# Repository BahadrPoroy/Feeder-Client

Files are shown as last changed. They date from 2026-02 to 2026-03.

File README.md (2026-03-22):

# 🕒 NetTime Ecosystem - Feeder Client (V1.2.0) 🐟






A **cloud-connected smart actuator node** based on **ESP8266**. This device is a critical peripheral in the NetTime ecosystem, responsible for executing automated feeding cycles and maintaining a persistent global state via **Firebase Realtime Database**.

## 🚀 What's New in v1.2.0
<!--### FIXES ###
- **`START_VAL`, `SPEED_LIMIT` and `REVERSE_VAL` values are refactored, `START_VAL` is increased to 125 from 120 for faster first movement and easier escaping, `SPEED_LIMIT` is reduced to 110 from 115 for more consistent stopping on switch also, `REVERSE_VAL` is increased to 70 from 60 for same reason as `SPEED_LIMIT`**
-->
### IMPROVEMENTS ###
<!--- **Detailed and improved fault detection system:**
    - ***In `dispensePortion` function, `millis()` based control used instead of `delay(2000)` for `non-blocking` principle. Added a fault control section to detect switch state changes..***
    - **Error detection messages has been improved from now on, they include more information *If the `switch released` control (the first one) detects an error, message includes `servo/switch error` notification else, if `is switch re-triggered` control detects an error the message includes `possible_servo_stuck` information***
- **`is switch re-triggered` control's timeout value is changed, now it's reduced to ten seconds for more reliable and realistic results**
- **Added a Restart function to automatically calibrate and return the servo to its home position upon system initialization or recovery.**
-->
   - **Integrated an RGB LED as a real-time status indicator. The system now provides visual feedback: flashing $\color{blue}{\text{blue}}$ during Wi-Fi negotiation, turning solid $\color{blue}{\text{blue}}$ once connected. Other states include $\color{red}{\text{red}}$ for hardware/software errors, $\color{yellow}{\text{yellow}}$ for pending operations, and $\color{green}{\text{green}}$ for successful task completion.**

### 🚀 Key Features

* **Asynchronous State Synchronization:** Monitors cloud-based triggers in real-time. It uses a **Universal State Template** to ensure the feeding status is synchronized across all dashboard clients.
* **Hardware Actuation:** Manages high-precision motor/servo control for the physical feeding mechanism.
* **Decoupled Architecture:** Operates as a standalone agent. While it integrates with the [NetTime-Env-Server](https://github.com/BahadrPoroy/NetTime-Env-Server), it can function independently through direct web-dashboard commands.
* **Persistent Event Logging:** Automatically stamps and uploads `lastFedTime` and `isFed` status to the cloud, ensuring data persistence even after power cycles.
* **Network Resilience:** Features an automated reconnection engine for both WiFi and Firebase services to prevent missed feeding cycles.
* **Status LED:** Integrated an RGB indicator to provide real-time visual feedback, significantly enhancing the `User Experience (UX)`.
---

### 🏗️ System Architecture

The Feeder Client follows the **Publisher-Subscriber** model:
1.  **Listen:** Subscribes to the `isFed` trigger on Firebase.
2.  **Act:** Once triggered, executes the motor rotation sequence.
3.  **Confirm:** Updates the database with the success timestamp and resets the trigger.

---

### 🛠️ Hardware Requirements

* **MCU:** ESP8266 (NodeMCU or Wemos D1 Mini)
* **Actuator:** MG90S Servo or Stepper Motor (Configurable in `HardwareConfig.h`)
* **Power:** 5V External DC (Recommended for motor stability)

---

### 🎨 Industrial Design & Prototyping

To ensure a professional and durable finish, the enclosures for all ecosystem nodes (Server, Feeder, and Display) were **custom-designed and 3D printed**.

* **Custom Enclosures:** Specifically tailored to house the ESP8266, sensors, and actuators while maintaining optimal airflow and structural integrity.
* **Rapid Prototyping:** Iterative design process to ensure perfect fitment for the MG90S servo and OLED mounts.
* **Integration:** The hardware is not just a circuit on a breadboard; it is a fully enclosed, desk-ready consumer electronics prototype.

---

## 📂 Project Structure

```
Feeder_Client
├── NetworkManager.h  # Firebase, WiFi, UDP & OTA Updates
```

---

🌐 The NetTime Ecosystem
This client is designed to work within the NetTime IoT Framework. While it can operate as a standalone node, it reaches its full potential when paired with other ecosystem components:

[NetTime-Env-Server](https://github.com/BahadrPoroy/NetTime-Env-Server): The central hub that provides localized time, environmental data, and acts as the primary network master.

[NetTime-Client-Display](https://github.com/BahadrPoroy/NetTime-Client-Display): A dedicated monitoring node that visualizes real-time climate data and synchronized time on a peripheral OLED/TFT display.

NetTime-Feeder-Client (This Repo): The ecosystem's actuator node, responsible for cloud-triggered hardware automation and persistent state logging.

[Web Dashboard](https://bahadrporoy.github.io/NetTime-Env-Server/): A real-time interface (integrated within the Server) that allows manual overrides and global monitoring of all connected clients.

---

### 🔧 Installation & Deployment

1.  **Clone** this repository.
2.  **Configure Credentials:** Create a `secrets.h` file based on the template provided.
3.  **Hardware Calibration:** Adjust motor sweep angles or steps in `config.h`.
4.  **Flash:** Deploy via Arduino IDE or PlatformIO.

---

### 📄 License
This project is licensed under the **MIT License**.

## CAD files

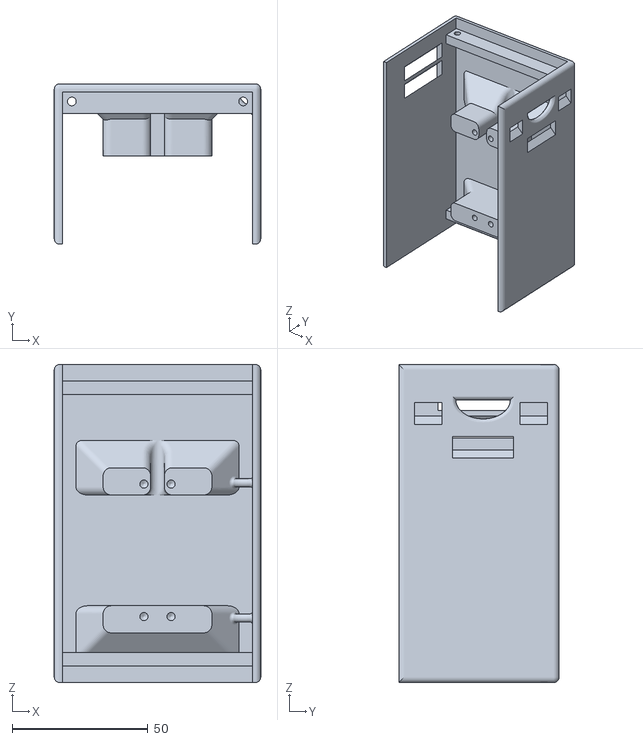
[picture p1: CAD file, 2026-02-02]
3d-models/Main_Body.STL
76.0 x 59.0 x 117.0

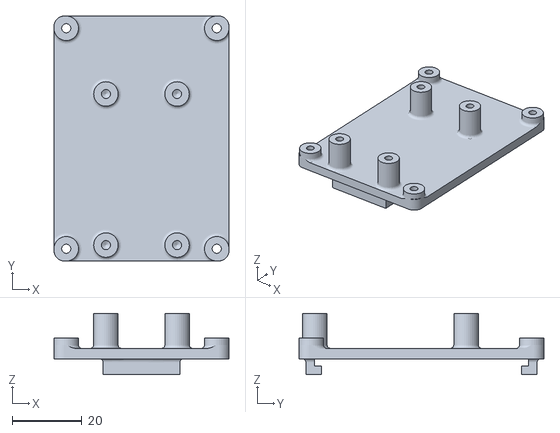
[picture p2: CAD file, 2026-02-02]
3d-models/Button_Base.STL
50.0 x 70.0 x 17.5

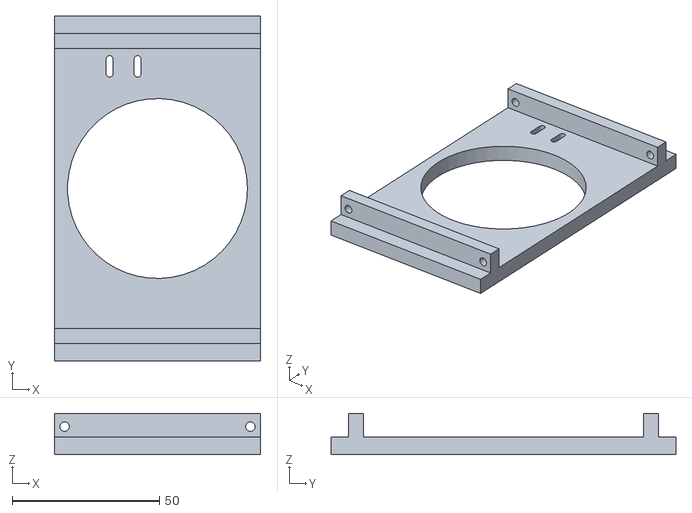
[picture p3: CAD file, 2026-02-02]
3d-models/Front_Panel.STL
70.0 x 117.0 x 14.0

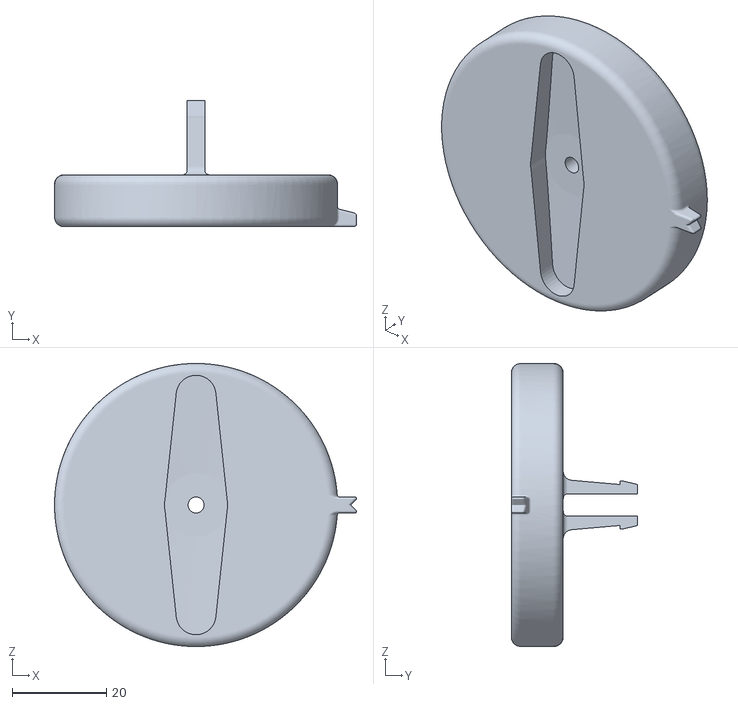
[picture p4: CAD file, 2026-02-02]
3d-models/Feeder_Coupler.STL
64.0 x 26.8 x 60.0

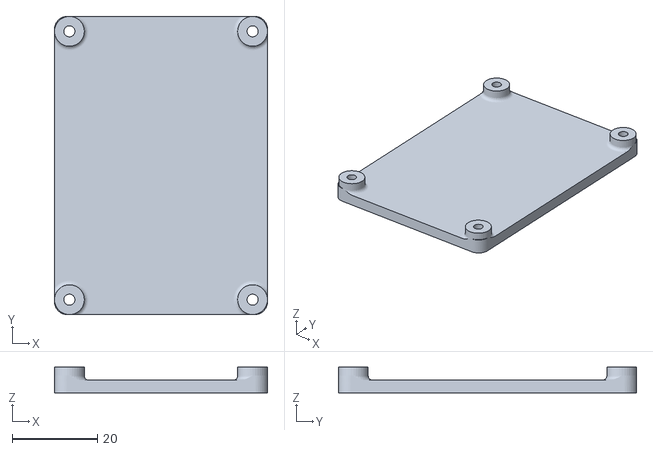
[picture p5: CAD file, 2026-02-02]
3d-models/Top_Cover.STL
50.0 x 70.0 x 6.00

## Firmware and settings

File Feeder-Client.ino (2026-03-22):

#include <ESP8266WiFi.h>
#include <WiFiUdp.h>
#include <ArduinoOTA.h>
#include <Servo.h>
#include <time.h>
#include "secrets.h"
#include "NetworkManager.h"

// --- Hardware Pins ---
const int SERVO_PIN = D2;
const int SWITCH_PIN = D1;  // D1 and GND connection
const int L_RED = D3;
const int L_GREEN = D5;
const int L_BLUE = D6;

Servo feederServo;
NetworkManager netBox;

// --- System Settings ---
String Status = "IDLE";
long int lastFirebaseSync = 0;
unsigned long lastPacketTime = 0;
int lastCheckDay = -1;
int lastCheckInterval = 0;
int dailyFeedCount = 10;
int dailyFeedLimit = 1;

// --- Servo Settings ---
const int STOP_VAL = 90;
const int START_VAL = 125;
const int REVERSE_VAL = 60;
const int SPEED_LIMIT = 110;

// --- Time Settings ---
struct tm timeinfo;
const char* ntpServer = "pool.ntp.org";
const long gmtOffset_sec = 3 * 3600;


void setup() {
  pinMode(L_RED, OUTPUT);
  pinMode(L_GREEN, OUTPUT);
  pinMode(L_BLUE, OUTPUT);
  netBox.begin();
  Serial1.begin(115200);
  Serial.begin(115200);

  configTime(gmtOffset_sec, 0, ntpServer);

  pinMode(SWITCH_PIN, INPUT_PULLUP);

  feederServo.attach(SERVO_PIN);

  Restart();  //Gets the servo to home position

  netBox.readFeedLimit(dailyFeedLimit);
  netBox.readFeedCount(dailyFeedCount);
  if (dailyFeedCount == dailyFeedLimit)
    netBox.broadcastUDP("SUCCESS");
}

void dispensePortion() {
  digitalWrite(L_RED, LOW);
  digitalWrite(L_GREEN, LOW);
  digitalWrite(L_BLUE, HIGH);
  if (dailyFeedCount >= dailyFeedLimit) {
    netBox.broadcastUDP("SUCCESS");
    digitalWrite(L_RED, HIGH);
    digitalWrite(L_GREEN, LOW);
    digitalWrite(L_BLUE, HIGH);
    return;
  }
  Status = "PENDING";
  netBox.broadcastUDP(Status);

  // --- Clearing The Switch Area ---

  unsigned long timeout = millis();

  while (millis() - timeout <= 2000) {
    feederServo.write(START_VAL);
  }
  // --- ~ ~ ~ ---

  if (digitalRead(SWITCH_PIN) == HIGH) {  //Controls the system for any stucks
    feederServo.write(STOP_VAL);
    Status = "ERROR_HARDWARE(Servo/Switch_Error)";
    netBox.broadcastUDP(Status);
    netBox.updateFirebase(Status);
    digitalWrite(L_RED, LOW);
    digitalWrite(L_GREEN, HIGH);
    digitalWrite(L_BLUE, HIGH);
    return;
  }

  timeout = millis();
  int slowFact = 0;

  while (digitalRead(SWITCH_PIN) == LOW) {
    if (millis() - timeout > 10000) {  // 10 second safety timeout
      Serial1.println("ERROR: Switch not triggered!");
      Status = "ERROR_HARDWARE(Possible_Servo_Stuck)";
      break;
    }
    feederServo.write(START_VAL - slowFact);
    slowFact++;
    if (START_VAL - slowFact <= SPEED_LIMIT) slowFact = START_VAL - SPEED_LIMIT;
    yield();
  }

  feederServo.write(STOP_VAL);  // Always stop

  if (Status == "PENDING") {
    Status = "SUCCESS";
    dailyFeedCount++;
    netBox.updateFirebase(dailyFeedCount);
  }

  netBox.broadcastUDP(Status);
  netBox.updateFirebase(Status);
  Serial1.print("Dispense finished with status: ");
  Serial1.println(Status);
  if (Status.startsWith("ERROR")) {  //Red
    digitalWrite(L_RED, LOW);
    digitalWrite(L_GREEN, HIGH);
    digitalWrite(L_BLUE, HIGH);
  } else if (Status == "SUCCESS") {  // Green
    digitalWrite(L_RED, HIGH);
    digitalWrite(L_GREEN, LOW);
    digitalWrite(L_BLUE, HIGH);
  } else {  // Yellow
    digitalWrite(L_RED, LOW);
    digitalWrite(L_GREEN, LOW);
    digitalWrite(L_BLUE, HIGH);
  }
}

void loop() {
  netBox.handleOTA();
  netBox.handleNetwork(Status, lastPacketTime);
  if (millis() - lastCheckInterval >= 1000) {
    lastCheckInterval = millis();
    time_t now = time(nullptr);
    localtime_r(&now, &timeinfo);
  }
  if (Status == "SUCCESS" && (millis() - lastPacketTime > 600000)) {
    Status = "IDLE";
    digitalWrite(L_RED, HIGH);
    digitalWrite(L_GREEN, LOW);
    digitalWrite(L_BLUE, LOW);
    netBox.broadcastUDP(Status);
    Serial1.println("Cooldown finished. System is IDLE again.");
  }
  if (millis() - lastFirebaseSync >= 20000) {
    lastFirebaseSync = millis();
    netBox.readFeedLimit(dailyFeedLimit);
  }
  if (timeinfo.tm_hour == 0 && timeinfo.tm_min == 0 && lastCheckDay != timeinfo.tm_wday) {
    lastCheckDay = timeinfo.tm_wday;
    Status = "IDLE";
    dailyFeedCount = 0;
    netBox.broadcastUDP(Status);
    netBox.updateFirebase(Status);
    netBox.updateFirebase(dailyFeedCount);
    digitalWrite(L_RED, HIGH);
    digitalWrite(L_GREEN, HIGH);
    digitalWrite(L_BLUE, LOW);
  }
}

void Restart() {
  unsigned long timeout = millis();
  while (digitalRead(SWITCH_PIN) == LOW) {
    feederServo.write(REVERSE_VAL);
    if (millis() - timeout > 15000) {  // 10 second safety timeout
      Serial1.println("ERROR: Switch not triggered!");
      Status = "ERROR_HARDWARE(Possible_Servo_Stuck)";
      break;
    }
    yield();
  }
  feederServo.write(STOP_VAL);  // Servo Initial State
  Status = "IDLE";
  netBox.broadcastUDP(Status);
  netBox.updateFirebase(Status);
  if (Status.startsWith("ERROR")) {
    digitalWrite(L_RED, LOW);
    digitalWrite(L_GREEN, HIGH);
    digitalWrite(L_BLUE, HIGH);
  } else {
    digitalWrite(L_RED, HIGH);
    digitalWrite(L_GREEN, HIGH);
    digitalWrite(L_BLUE, LOW);
  }
}

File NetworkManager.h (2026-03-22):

#ifndef NETWORK_MANAGER_H
#define NETWORK_MANAGER_H

#include <ESP8266WiFi.h>
#include <FirebaseESP8266.h>
#include <ArduinoOTA.h>
#include <WiFiUdp.h>
#include <ESP8266HTTPClient.h>
#include <WiFiClientSecure.h>
#include <ArduinoJson.h>
#include "secrets.h"

extern void dispensePortion();
extern void Restart();
extern const int L_RED;
extern const int L_BLUE;
extern const int L_GREEN;

class NetworkManager {
private:
  FirebaseData firebaseData;
  FirebaseConfig config;
  FirebaseAuth auth;
  WiFiUDP udp;

  //Seperated ports for diffrent purposes
  unsigned int INCOMING_PORT = 4210;  //Listening port for Client
  unsigned int OUTGOING_PORT = 4211;  //Sending port for Client
                                      /**
   * @brief Fetches weather data from OpenWeather API using stream parsing to save RAM
   */

public:

  void begin() {
    digitalWrite(L_RED, HIGH);
    digitalWrite(L_GREEN, HIGH);
    digitalWrite(L_BLUE, HIGH);
    int now = millis();
    WiFi.mode(WIFI_STA);
    WiFi.begin(YOUR_SSID, YOUR_PASS);

    Serial.print("Connecting to WiFi");
    while (WiFi.status() != WL_CONNECTED) {
      if (millis() - now >= 500) {
        digitalWrite(L_BLUE, !digitalRead(L_BLUE));
        now = millis();
      }
      delay(10);
    }
    Serial.println("\nWiFi Connected");
    digitalWrite(L_BLUE, LOW);

    config.host = YOUR_URL;
    config.signer.tokens.legacy_token = YOUR_DATABASE_SECRET_KEY;
    Firebase.begin(&config, &auth);
    Firebase.reconnectWiFi(true);

    ArduinoOTA.setHostname("Feeder_Client");
    ArduinoOTA.setPassword(YOUR_OTA_PASS);

    ArduinoOTA.begin();
    udp.begin(INCOMING_PORT);
  }

  void updateFirebase(const String &Status) {
    Firebase.setString(firebaseData, "/FeederStatus/Status", Status);
  }

  void updateFirebase(const int &feedCount) {
    Firebase.setInt(firebaseData, "/FeederStatus/FeedCount", feedCount);
  }

  void readFeedCount(int &feedCount, int i = 0) {
    if (Firebase.getInt(firebaseData, "/FeederStatus/FeedCount")) {
      feedCount = firebaseData.intData();
      Serial1.println("FeedCount Alındı");
      return;
    } else if (i == 5) {
      return;
    } else {
      i++;
      readFeedCount(feedCount, i);
      Serial1.println("FeedCount Alınmadı");
    }
  }

  void readFeedLimit(int &dailyFeedLimit, int i = 0) {
    if (Firebase.getInt(firebaseData, "/FeederStatus/FeedLimit")) {
      dailyFeedLimit = firebaseData.intData();
      Serial1.println("FeedLimit Alındı");
      return;
    } else if (i == 5) {
      return;
    } else {
      i++;
      readFeedLimit(dailyFeedLimit, i);
      Serial1.println("FeedLimit Alınmadı");
    }
  }

  void broadcastUDP(String message) {
    IPAddress broadcastIP = WiFi.localIP();
    broadcastIP[3] = 255;
    udp.beginPacket(broadcastIP, OUTGOING_PORT);  //Updated
    udp.write(message.c_str());
    udp.endPacket();
  }

  void handleOTA() {
    ArduinoOTA.handle();
  }

  void handleNetwork(String &Status, unsigned long &lastPacketTime) {
    int packetSize = udp.parsePacket();
    if (packetSize) {
      char buf[255];
      int len = udp.read(buf, 254);
      if (len > 0) buf[len] = 0;
      String req = String(buf);
      req.trim();

      Serial1.print("Paket yakalandi: ");
      Serial1.println(req);

      // Feeding Control
      if (req == "FEED_NOW") {
        unsigned long currentTime = millis();
        if (Status.startsWith("ERROR")) {
          Serial1.println("BLOCK: Hardware error persistent. Manual reset required.");
          broadcastUDP(Status);
        } else if (Status == "PENDING" || Status == "SUCCESS" || (currentTime - lastPacketTime < 2000)) {
          Serial1.print("Protection Triggered: Skipping duplicate/invalid request. Status: ");
          Serial1.println(Status);
          lastPacketTime = currentTime;
        } else {
          // Only turn the servo if the status is "IDLE" or "SW/NETWORK_ERROR"
          lastPacketTime = currentTime;
          dispensePortion();
        }
      }
      if (req == "RESTART") {
        Restart();
      }
    }
  }
};
#endif

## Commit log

2026-02-02 feat: initial release of standalone Feeder Client v1.0.0-alpha
    - Established modular project structure with dedicated headers for Firebase and Motor control.
    - Implemented real-time state synchronization via Firebase Realtime Database.
    - Added asynchronous motor actuation logic with configurable hardware abstraction.
    - Integrated automated WiFi reconnection and OTA update support.
    - Initialized documentation with comprehensive README.
    [Button_Base.STL, Feeder_Coupler.STL, Front_Panel.STL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]
2026-02-16 feat(feeder): release v1.1.0 - implement robust safety logic and architectural cleanup
    - Version bump to v1.1.0: First stable release with multi-layer protection.
    - Added 3-layer safety: Hardware timeout, State protection, and Network debounce.
    - Implemented 2-second network filter to prevent duplicate feeding from UDP ghost packets.
    - Enhanced hardware safety: Added a 50s failsafe to lock the system if the switch fails.
    - Integrated automated Firebase and UDP status reporting for cloud/local sync.
    - Refactored dispensePortion() for a cleaner, single-exit-point logic.
    - Implemented 10-minute cooldown period to ensure system stability between feeds.
    - Removed legacy code, redundant variables,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
    [Feeder-Client.ino, NetworkManager.h]
2026-03-09 Feat(Controls-Logic):AddMore Reliable Controls for Preventing to Overfeeding
    ## What's New:
    ** A new item added to database named as FeedLimit. It keeps maximum feeding count that changable by user.
    **Two new variables added to code called as dailyFeedLimit and dailyFeedCount. First one keeps the data read from database, second one keeps the count of feeding circles daily.
    ***The New Logic***
    On every feeding circle (call of dispensePortion with success) feed counter is increasing, if it would be equal to feed limit function directly returns without feeding.
    [Feeder-Client.ino, NetworkManager.h]
2026-03-22 Status Led Added for Improved UX
2026-03-22 V1.2.0: Improved UX
    feat: Integrated an RGB LED as a status indicator. It flashes blue during Wi-Fi negotiation and turns solid blue once connected. Red, yellow, and green represent other system states (detailed descrip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

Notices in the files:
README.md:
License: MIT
